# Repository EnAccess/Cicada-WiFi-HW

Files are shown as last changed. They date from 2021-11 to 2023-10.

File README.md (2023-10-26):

<p align="center">
  <a href="https://github.com/EnAccess/Cicada-WiFi-HW">
    Cicada GSM
  </a>
</p>
<p align="center">
    <em>IoT Communications Module for Energy Access. A quick way to get production ready, bi-directional communications for your IoT embedded device.</em>
</p>
<p align="center">
  
  
  <a href="https://github.com/EnAccess/Cicada-WiFi-HW/blob/main/LICENSE" target="_blank">
    
  </a>
</p>

---

# Cicada-WiFi-HW

Cicada WiFi HW - IoT Communications Module for Energy Access.
An easy way to get production ready, bi-directional communications for your IoT embedded device.

This repository contains the hardware design for supported Cicada wifi. This HW is designed to operate with host running cicada-FW. <https://github.com/EnAccess/Cicada-FW>

## Manufacturing files

If you are only interested in manufacturing the PCBs, you only need files in the /manufacturing/ directory. send them to your contract manufacturer of choice,Some examples of other turnkey PCBA manufacturers are:

| Manufacturers |
|---------------|
| JLCPCB |
| PCBCart |
| Bittele |

you can also get a plug and play module (might require manual FW update) from <https://www.seeedstudio.com/Enaccess-Okra-Cicada-Wifi-Communication-PCBA-p-5421.html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>.

The /manufacturing/production directory contains the PCB Gerber/drill files, the BOM, and assembly instructions.

## Source files

If you'd like to take a look at the schematics and PCB layout, first, make sure you have a fresh version of KiCAD. It's a free and open source electronics design tool,
and can be downloaded from <http://kicad.org>. Make sure you are not using an old version that some Linux distributions might be still shipping.

## File structure

The schematics and related files live under the /design/ directory:

| Directory | Content |
|---|---|
| /design/doc/datasheets/ | Datasheets for some of the components used. These files are not covered by this project's open source licence |
| /design/doc/Schematic | Schematics exported as PDF. |
| /design/source/kicad/ | Kicad source files for the CICADA WIFI hardware inculding component lib files and bom generation script |
| /manufacturing/gerber/ |  these are set of files which gives information on different layers used in the project (copper layers, silk screen , court yard and other relevent files) |
| /manufacturing/stackup/ | Text file containing the details of the PCB material and stackup |
| /manufacturing/pick and place/ | Pick and place files describing component locations and orientations for PCB Assembly |
| /manufacturing/nc drill/ | NC Drill files describing type and specification of PCB drill holes (vias, through holes, mounting holes etc) |
| /manufacturing/BOM/ | BOM contains the imformation of all the components used in WiFi cicad. directely generated from Kicad using the bom genration script  |

## A quick look at the schematics

The schematics is based on ESP-07S ESP8266 Serial WiFi Module, The module supports standard IEEE802.11 b/g/n agreement, complete TCP/IP protocol stack and capable of
+20dBm output power in 802.11b mode. For more information the data sheet of the module will be available in /design/doc/datasheets/ directory

## Host interface

The Cicada uses a 2x10 female pin socket that fits perfectly in a 2x8 shrouded pin header on the host side. (We don’t use a 2x8 female pin socket because it is possible to
do a off-by-one insertion with it). The host interface provides a way for the host to detect the presence of a Cicada board,transmit and receive data, and distinguish
between different Cicada communications boards (Cicada 2g, Cicada 4g):

| Pin | Discription |
|---|---|
| Pin-1 Vref(3v3) | Logic level VCC reference provided by host. only used for VER_1/2 as described below. Other cicadas Vref may be used for level shifiting for I/O pins |
| Pin-2 VER_1 | Board version pin (represents, what type of cicada it is 2g,4g or WiFi), for more information please check schematics |
| Pin-3 GND |  |
| Pin-4 VER_2 | Board version pin (represents, latest production release version) |
| Pin-5 5V | 5v Power provided by host. Peak curent consuption <200mA |
| Pin-6 GND |  |
| Pin-7 GND |  |
| Pin-8 POWER_EN | Drive high to enable power |
| Pin-9 NC |  |
| Pin-10 NC |  |
| Pin-11 NC |  |
| Pin-12 UART_Tx_3V3 | Should be connected to host's UART_TX |
| Pin-13 UART_Rx_3V3 | Should be connected to host's UART_RX |
| Pin-14 MODE_SELECT |  Pull low to Enable ESP-8266 FW flashing mode, |
| Pin-15 NC |  |
| Pin-16 n_RESET| drive low to reset, drive at 1.8 - 3.3v during normal operation |

## Power

Board is powered up by single-chip SMPS (HX3406) to convert 5v down to 3.3v required by ESP-07S(ESP8266 Serial WiFi Module WiFi module).

## Antenna

The ESP-07S ESP8266 Serial WiFi Module has a on board IPEX connector, which can be extended to an antenna using U.FL cable

## ESP8266 operating MODEs

| ESP8266 operating MODE  | GPIO15 | GPIO0 | GPIO2 |
|---|---|---|---|
| FW flashing | low | low | high |
| Normal/UART | low | high | high |

# Need to Flash the module with the latest FW??

## Requirements

- USB to serial TTL adapter hardware
- esptool.py (Ubuntu package esptool or GitHub - espressif/esptool: Espressif SoC serial bootloader utility)
- Wifi firmware: <https://www.espressif.com/sites/default/files/ap/ESP8266_NonOS_AT_Bin_V1.7.4.zip>
Note: Make sure the USB to serial adapter is set to 3.3V IO voltage! (usually there is a jumper for that)

## Setup

Connect Wifi module and USB adapter

| Cicada WiFi | USB adapter |
|---|---|
| 5V0 | 5V0 |
| GND | GND |
| POWER_EN | 3V3 |
| UART_RX_3V3 | Rx |
| UART_TX_3V3 | Tx |
| MODE_SELECT | GND |

The module should now respond to AT commands. You can check this by running the serial_linux example from Cicada.

## Flash firmware

- Unzip the firmware package and go to ESP8266_NonOS_AT_Bin_V1.7.4/bin directory. Then run this command to flash:
esptool.py -p /dev/ttyUSB0 --chip esp8266 write_flash --flash_size 4MB-c1 0x00000 boot_v1.7.bin 0x01000 at/1024+1024/user1.2048.new.5.bin 0x1fc000   esp_init_data_default_v08.bin 0xfe000 blank.bin 0x1fb000 blank.bin 0x1fe000 blank.bin

After flashing, remove the grounding of IO0(MODE_SELECT) again, so it’s free floating. The Cicada module should now be ready for installation.

# Future Improvements

- invitigate on adding an amplifier to the design for range improvemnet

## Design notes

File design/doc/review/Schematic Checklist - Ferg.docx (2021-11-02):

# Schematic Design Review checklists

Part / Assembly | P-1000072
Revision
Review Date
Review Type
Reviewed By

# Schematic Review

# | Check | Completed | Comment

| Individual Components
| Component links match footprint and annotations
| All nets are limited to below the max V, I etc of the component | Y
| Adequate filtering is provided where needed. Consider ferrites, series resistors and TVS on signals going externally. Consider filtering on power lines, esp is low noise power is needed for analog signals | y
| Race conditions checked | y
| Starts up into known/controlled state | y
| Layout notes are present where required | y
| Differential pairs specified where necessary | y
| Compare to ref. design if available | y
| All pins connected to sensible things | y
| Polarisation checked | y
| Power Lines
| Input power lines fused and protected | na
| For automotive use, Two ceramic capacitors placed in series across input lines and at right angles to each other. | na
| Power limiting behaviour verified | na
| Power supplies are adequate | y
| IO
| Check pinouts for all external connectors match the connector they mate with | y
| All outside lines filtered for RFI | y
| All necessary lines protected against static discharge | y
| Other
| Overview sheet is present | na
| Behaviour of entire schematic as expected | y
| No 4 way joins, all other nets are joined where they should be | y
| Test points where required | y
| Signal LEDs where required | y
| Debug headers for signals that may need external access | y
| Confirm I2C has pull ups | na
| Confirm Tx/Rx nets swapped as necessary (for UART, PCIe, etc etc) | y
| Component Selection
| Temp Grade
| Ratings (eg automotive)
| Suitable Functionality
| Thermal Dissipation
| Thermal Derating
| Current Handling
| Voltage
| DC Bias (Cap and Inductor)
| DNPs

# Review Area

# | Sheet | Component/Net | Type | Comment | Recommended action | Designers response /action taken | Review Response | Designers response /action taken 2

| | All | | Sch isn’t readable in some areas. Sch should be super easy to ready, it’s purpose is to convey the function of the circuit as quickly, easily, and unambigiously to the ready as possible | No overlapping text, good spacing, minimise unlinked net label etc | Done | Looks ok, more spacing never really hurts. Also making sure labels are in consistent location and orientation makes things more readable.
| | R7/R10 | | Do we need these? I think they will just mess up the signal path? | | | ok
| | L3/L4 | | Should these be between caps and U2, or should the caps be between U2 and L3/4? | | I have followed the reference design, which chee has used for review, but it was not using the same IC though | ok
| | U3 | | Add decoupling caps next to U3 | I would add a couple of 1uF and 0.1uF caps next to ESP-07S VCC | Added | ok
| | U3 | | U3 EN signal should have 0R resistor | | Followed ESPWROOM-02U datasheet and added RC network, as it was recommended | ok
| | U3 | | Add a series 22R or 100R resistor to the UART Tx and Rx lines. These can be used to improve signal quality and to protect the device in case of MCU failure or something | | Done Looks like it’s been taken care on MCU side | ok
| | VCC | | Rename VCC net to 3V3 | | Done | ok
| | 5v | | Rename to 5V0 | | Done | Missed one lower case ‘v’ 3v3 on U3 EN pin
| | U1 | | Add output current rating next to output (800mA?) | | Done | ok
| | J1 | | Change name of 3v3 to indicate it is only for level shifting purposes | | Done | ok
| | Electrical Char section | | This is awesome, I would rename it power consumption, Add the 800mA output limit of the HX3406, (and possibly put it down near the PSU section?) | | Done | ok
| | U2 | | Was there an app not for this chip that you referenced? | | I have followed the reference design, which chee has used for review, but it was not using the same IC though. https://okrasolar.slack.com/archives/CERGXCN8K/p1629262801000400?thread_ts=1629091767.000800&cid=CERGXCN8K | ok
| | D1 | | Adding ESD diode is a very good call (the SE2604L states it is an ESD sensitive device). Should we add one to the RF input as well? (most assembly should be in ESD safe env, but given this is an oen source design it might be better same than sorry | | Done | Ok. I’m not sure if we will want to load the 100pf caps on the rf lines.. Are they part of the App note?
| | U2/R11 | | We should add a DNP 1k pull up resistor here as well in case we just want to have it enable all the time. U2 also has a build in 10k pull down on the pin so we could possible get rid of R11 (or at least DNP) | | Done | ok
| | TP30 | | I would put the pair of bottom side (and one top side) GND test points in the power section as they are one of the “Power” nets | | TP30 is not a ground | There are a bunch of GND test points on the GND pins from each IC, I would suggest putting the power test points in the power section for clarity?
| | U2 | | Add a layout note saying that the RF path needs to be single ended 50R controlled impedance tracks, and that the tracs should be as should as possible and follow RF layout best practice. | | Will do while working on layout | Can we add the note to the Sch? The idea is to have the layout note on the Sch so that if someone else needs to make layout changes later they have all the needed info.
| | Logos | | Can we add an open hardware logo? | | Not sure what I should do here! | Low priority, don’t worry about it
| | D1 | | Value should be set to MPN | | Done
| | J3 Host connector | | Pin14 in NC on edamame. | | Move mode select to pin 15 (nCS pin on edamame)
| | U1 Pin 5 | | 4-way ‘+’ net connection off U1 pin 5 is not recommended as the circle can hide a missed connection. | | Change it to two three way ‘T’ joins

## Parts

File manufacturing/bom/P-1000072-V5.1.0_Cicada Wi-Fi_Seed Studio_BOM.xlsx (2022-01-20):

Designator | MNP | Qty | Link | Description | Manufacturer | SMT/THT | Source | SPN
C1, C2, C21, C22, C24 | GR108M010F12RR0VL4FP0 | 5 | https://www.lcsc.com/product-detail/Aluminum-Electrolytic-Capacitors-Leaded_CX-Dongguan-Chengxing-Elec-GR108M010F12RR0VL4FP0_C3299.html | 1000uF 10v | Dongguan Chengxing Elec | THT | lcsc | C3299
C3, C19 | 0603B104K500NT | 2 | https://www.lcsc.com/product-detail/Multilayer-Ceramic-Capacitors-MLCC-SMD-SMT_FH-Guangdong-Fenghua-Advanced-Tech-0603B104K500NT_C30926.html | 100nF 16v X7R | Guangdong Fenghua Advanced Tech | SMT | lcsc | C30926
C4, C20 | 0805B106K160NT | 2 | https://www.lcsc.com/product-detail/Multilayer-Ceramic-Capacitors-MLCC-SMD-SMT_FH-Guangdong-Fenghua-Advanced-Tech-0805B106K160NT_C92341.html | 10uF 16v X7R | Guangdong Fenghua Advanced Tech | SMT | lcsc | C92341
C6, C8, C14, C29 | CC0402MRX5R6BB104 | 4 | https://www.lcsc.com/product-detail/Multilayer-Ceramic-Capacitors-MLCC-SMD-SMT_YAGEO-CC0402MRX5R6BB106_C962143.html | 100nF 10v X5R | Yageo | SMT | lcsc | C2171572
C9 | CC0402MRX5R6BB106 | 1 | https://www.lcsc.com/product-detail/Multilayer-Ceramic-Capacitors-MLCC-SMD-SMT_YAGEO-CC0402MRX5R6BB106_C962143.html | 10uF 10v X5R | Yageo | SMT | lcsc | C962143
C16 | 0402CG101J500NT | 1 | https://www.lcsc.com/product-detail/Multilayer-Ceramic-Capacitors-MLCC-SMD-SMT_FH-Guangdong-Fenghua-Advanced-Tech-0402CG101J500NT_C1546.html | 100pF C0G | Guangdong Fenghua Advanced Tech | SMT | lcsc | C1546
J3 | C30867 | 1 | https://www.lcsc.com/product-detail/Female-Headers_BOOMELE-Boom-Precision-Elec-C30867_C30867.html | Host | Boom Precision Elec | THT | lcsc | C30867
L2 | FPI0403F-3R3M | 1 | https://www.lcsc.com/product-detail/Inductors-SMD_SHOU-HAN-CY43-3-3UH_C2929417.html | 3.3uH 2.1A | SHOU HAN | SMT | lcsc | C2929417
R1, R7 | 0402WGF4022TCE | 2 | https://www.lcsc.com/product-detail/Chip-Resistor-Surface-Mount_UNI-ROYAL-Uniroyal-Elec-0402WGF4022TCE_C25893.html | 40.2k | Uni-Royal | SMT | lcsc | C25893
R4, R5, R11 | 0402WGF1002TCE | 3 | https://www.lcsc.com/product-detail/Chip-Resistor-Surface-Mount_UNI-ROYAL-Uniroyal-Elec-0402WGF1002TCE_C25744.html | 10K | Uni-Royal | SMT | lcsc | C25744
R6 | 0402WGJ0000TCE | 1 | https://www.lcsc.com/product-detail/Chip-Resistor-Surface-Mount_UNI-ROYAL-Uniroyal-Elec-0402WGJ0000TCE_C21376.html | 0R | Uni-Royal | SMT | lcsc | C21376
R8 | 0402WGF8871TCE | 1 | https://www.lcsc.com/product-detail/Chip-Resistor-Surface-Mount_UNI-ROYAL-Uniroyal-Elec-0402WGF8871TCE_C36953.html | 8.87k | Uni-Royal | SMT | lcsc | C36953
R9, R10 | 0402WGF220JTCE | 2 | https://www.lcsc.com/product-detail/Chip-Resistor-Surface-Mount_UNI-ROYAL-Uniroyal-Elec-0402WGF220JTCE_C25092.html | 22R | Uni-Royal | SMT | lcsc | C25092
R12 | 0402WGF2262TCE | 1 | https://www.lcsc.com/product-detail/Chip-Resistor-Surface-Mount_UNI-ROYAL-Uniroyal-Elec-0402WGF2262TCE_C26960.html | 22.6K | Uni-Royal | SMT | lcsc | C26960
R13 | 0402WGF8662TCE | 1 | https://www.lcsc.com/product-detail/Chip-Resistor-Surface-Mount_UNI-ROYAL-Uniroyal-Elec-0402WGF8662TCE_C19709.html | 86.6k | Uni-Royal | SMT | lcsc | C423187
U1 | HX3406 | 1 | https://datasheet.lcsc.com/lcsc/1912111437_HX-hengjiaxing-HX3406_C296282.pdf | 3V3, 800mA DC-DC Converter | XI'AN Aerosemi Tech | SMT | lcsc | C83224
U3 | ESP-07S | 1 | https://www.lcsc.com/product-detail/WiFi-Modules_Ai-Thinker-ESP-07S_C82895.html | ESP-07S WiFi Module | Ai-Thinker | SMT | lcsc | C82895

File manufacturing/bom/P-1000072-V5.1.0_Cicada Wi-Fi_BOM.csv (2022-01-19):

Source: | F:\office\okra\okrasolar\svn\P-1000072_Cicada Wi-Fi\design\source\kicad\P-1000072_Cicada Wi-Fi.sch
Date: | 1/19/2022 1:28:17 PM
Tool: | Eeschema (5.1.10)-1
Generator: | F:\office\okra\okrasolar\svn\okra_kicad_lib\scripts/OKRA_bom_csv_grouped_by_value_mpn_dnp.py
Component Count: | 34
Collated Components:
Designator | Qty | DNP | Value | Description | Manufacturer | MPN | Footprint | SMT/THT | SOURCE | SRCPN | Alternate Manufacturer 1 | Alternate MPN 1 | Alternate Manufacturer 2 | Alternate MPN 2
C1, C2, C21, C22, C24 | 5 |  | 1000uF 10v |  | Dongguan Chengxing Elec | GR108M010F12RR0VL4FP0 | Capacitor_THT:CP_Radial_D8.0mm_P3.50mm | THT | lcsc | C3299
C3, C19 | 2 |  | 100nF 16v X7R |  | Guangdong Fenghua Advanced Tech | 0603B104K500NT | Capacitor_SMD:C_0603_1608Metric | SMT | lcsc | C30926
C4, C20 | 2 |  | 10uF 16v X7R |  | Guangdong Fenghua Advanced Tech | 0805B106K160NT | Capacitor_SMD:C_0805_2012Metric | SMT | lcsc | C92341
C6, C8, C14, C29 | 4 |  | 100nF 10v X5R |  | YAGEO | CC0402MRX5R6BB104 | Capacitor_SMD:C_0402_1005Metric | SMT | lcsc | C2171572
C9 | 1 |  | 10uF 10v X5R |  | YAGEO | CC0402MRX5R6BB106 | Capacitor_SMD:C_0402_1005Metric | SMT | lcsc | C962143
C16 | 1 |  | 100pF C0G |  | Guangdong Fenghua Advanced Tech | 0402CG101J500NT | Capacitor_SMD:C_0402_1005Metric | SMT | lcsc | C1546
H1, H2 | 2 | DNP | MountingHole_Pad |  |  |  | MountingHole:MountingHole_3.2mm_M3_ISO14580_Pad | N/A
J3 | 1 |  | Host | Generic 2x10 2.54mm Female | Boom Precision Elec | C30867 | Cicada-footprints:PinSocket_2x08_P2.54mm_Vertical_padded | THT | lcsc | C30867
L2 | 1 |  | 3.3uH 2A |  | TAITEC | FPI0403F-3R3M | Cicada-footprints:L_4030_Handsoldering | SMT | lcsc | C304284
LOGO1 | 1 | DNP | SYM_Hot_Small |  |  |  | Cicada-footprints:okra_logo_copper_2 | N/A
PCB1 | 1 | DNP | WiFi Cicada PCB |  |  |  |  | N/A
R1, R7 | 2 |  | 40.2k | 1%,100ppm | UNI ROYAL | 0402WGF4022TCE | Resistor_SMD:R_0402_1005Metric | SMT | lcsc | C25893
R4, R5, R11 | 3 |  | 10K | 1%, 100ppm | UNI-ROYAL | 0402WGF1002TCE | Resistor_SMD:R_0402_1005Metric | SMT | lcsc
R6 | 1 |  | 0R | 5% 100ppm | UNI-ROYAL | 0402WGJ0000TCE | Resistor_SMD:R_0402_1005Metric | SMT | lcsc | C21376
R8 | 1 |  | 8.87k | 1% 100ppm | UNI ROYAL | 0402WGF8871TCE | Resistor_SMD:R_0402_1005Metric | SMT | lcsc | C36953
R9, R10 | 2 |  | 22R |  | UNI ROYAL | 0402WGF220JTCE | Resistor_SMD:R_0402_1005Metric | SMT | lcsc | C25092
R12 | 1 |  | 22.6K | 1% 100ppm | UNI ROYAL | 0402WGF2262TCE | Resistor_SMD:R_0402_1005Metric | SMT | lcsc | C26960
R13 | 1 |  | 86.6k | 1% 100ppm | UNI ROYAL | 0402WGF8662TCE | Resistor_SMD:R_0402_1005Metric | SMT | lcsc | C423187
U1 | 1 |  | HX3406 |  | XI'AN Aerosemi Tech | HX3406 | Package_TO_SOT_SMD:TSOT-23-5 | SMT | lcsc | C83224
U3 | 1 |  | ESP-07S |  | Ai-Thinker | ESP-07S | Cicada-footprints:ESP-07S | SMT | lcsc | C82895

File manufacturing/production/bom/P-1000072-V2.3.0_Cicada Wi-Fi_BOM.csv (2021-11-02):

Source: | F:\office\okra\okrasolar\svn\P-1000072_Cicada Wi-Fi\design\source\kicad\P-1000072_Cicada Wi-Fi.sch
Date: | 9/17/2021 9:25:19 AM
Tool: | Eeschema (5.1.10)-1
Generator: | F:\office\okra\okrasolar\svn\okra_kicad_lib\scripts/OKRA_bom_csv_grouped_by_value_mpn_dnp.py
Component Count: | 58
Collated Components:
Designator | Qty | DNP | Value | Description | Manufacturer | MPN | Footprint | SMT/THT | SOURCE | SRCPN | Alternate Manufacturer 1 | Alternate MPN 1 | Alternate Manufacturer 2 | Alternate MPN 2
C1 | 1 | DNP | 1000uF 10v |  | Dongguan Chengxing Elec | GR108M010F12RR0VL4FP0 | Capacitor_THT:CP_Radial_D8.0mm_P3.50mm | THT | lcsc | C3299
C2, C21, C22, C24 | 4 |  | 1000uF 10v |  | Dongguan Chengxing Elec | GR108M010F12RR0VL4FP0 | Capacitor_THT:CP_Radial_D8.0mm_P3.50mm | THT | lcsc | C3299
C3, C19 | 2 |  | 100nF 16v X7R |  | Guangdong Fenghua Advanced Tech | 0603B104K500NT | Capacitor_SMD:C_0603_1608Metric | SMT | lcsc | C30926
C4, C20 | 2 |  | 10uF 16v X7R |  | Guangdong Fenghua Advanced Tech | 0805B106K160NT | Capacitor_SMD:C_0805_2012Metric | SMT | lcsc | C92341
C5, C6, C8, C12, C14, C17, C26, C29 | 8 |  | 100nF 10v X5R |  | YAGEO | CC0402MRX5R6BB104 | Capacitor_SMD:C_0402_1005Metric | SMT | lcsc | C2171572
C7, C28 | 2 | DNP | 100pF C0G |  |  |  | Capacitor_SMD:C_0402_1005Metric
C9, C13, C15, C27 | 4 |  | 10uF 10v X5R |  | YAGEO | CC0402MRX5R6BB106 | Capacitor_SMD:C_0402_1005Metric | SMT | lcsc | C962143
C10, C23 | 2 | DNP | 10pF C0G |  |  |  | Capacitor_SMD:C_0402_1005Metric
C11, C16, C18, C25 | 4 |  | 100pF C0G |  | Guangdong Fenghua Advanced Tech | 0402CG101J500NT | Capacitor_SMD:C_0402_1005Metric | SMT | lcsc | C1546
D1, D2 | 2 |  | LXES15AAA1-153 |  | Murata Electronics | LXES15AAA1-153 | Diode_SMD:D_0402_1005Metric | SMT | lcsc | C86141
H1, H2 | 2 | DNP | MountingHole_Pad |  |  |  | MountingHole:MountingHole_3.2mm_M3_ISO14580_Pad | N/A
J1, J2 | 2 |  | U.FL |  | Hirose | U.FL-R-SMT-1(80) | edemame-custom-footprints:U.FL_Molex_MCRF_73412-0110_Vertical | SMT | lcsc | C88374
J3 | 1 |  | Host | Generic 2x10 2.54mm Female | Boom Precision Elec | C30867 | edemame-custom-footprints:PinSocket_2x08_P2.54mm_Vertical_padded | THT | lcsc | C30867
L1 | 1 |  | 1.2nH |  | Guangdong Fenghua Advanced Tech | VHF100505H1N2ST | Capacitor_SMD:C_0402_1005Metric | SMT | lcsc | C90187
L2 | 1 |  | 3.3uH 2A |  | TAITEC | FPI0403F-3R3M | edemame-custom-footprints:L_4030_Handsoldering | SMT | lcsc | C304284
L3 | 1 |  | 1nH |  | Guangdong Fenghua Advanced Tech | VHF100505HQ1N0ST | Capacitor_SMD:C_0402_1005Metric | SMT | lcsc | C395051
L4 | 1 |  | 10nH |  | WE | 7447860110 | Capacitor_SMD:C_0603_1608Metric | SMT | Digi-key | 732-7447860110TR-ND
LOGO1 | 1 | DNP | SYM_Hot_Small |  |  |  | edemame-custom-footprints:okra_logo_copper_2 | N/A
PCB1 | 1 | DNP | WiFi Cicada PCB |  |  |  |  | N/A
R1, R7 | 2 |  | 40.2k | 1%,100ppm | UNI ROYAL | 0402WGF4022TCE | Resistor_SMD:R_0402_1005Metric | SMT | lcsc | C25893
R2, R6 | 2 |  | 0R | 5% 100ppm | UNI-ROYAL | 0402WGJ0000TCE | Resistor_SMD:R_0402_1005Metric | SMT | lcsc | C21376
R3 | 1 |  | 1K | 1%, 100ppm | UNI-ROYAL | 0402WGJ0102TCE | Resistor_SMD:R_0402_1005Metric | SMT | lcsc | C25543
R4, R5, R11 | 3 |  | 10K | 1%, 100ppm | UNI-ROYAL | 0402WGF1002TCE | Resistor_SMD:R_0402_1005Metric | SMT | lcsc
R8 | 1 |  | 8.87k | 1% 100ppm | UNI ROYAL | 0402WGF8871TCE | Resistor_SMD:R_0402_1005Metric | SMT | lcsc | C36953
R9, R10 | 2 |  | 22R |  | UNI ROYAL | 0402WGF220JTCE | Resistor_SMD:R_0402_1005Metric | SMT | lcsc | C25092
R12 | 1 |  | 22.6K | 1% 100ppm | UNI ROYAL | 0402WGF2262TCE | Resistor_SMD:R_0402_1005Metric | SMT | lcsc | C26960
R13 | 1 | DNP | 22.6K | 1% 100ppm | UNI ROYAL | 0402WGF2262TCE | Resistor_SMD:R_0402_1005Metric | SMT | lcsc | C26960
U1 | 1 |  | HX3406 |  | XI'AN Aerosemi Tech | HX3406 | Package_TO_SOT_SMD:TSOT-23-5 | SMT | lcsc | C83224
U2 | 1 |  | SE2604L |  | SkyWork | SE2604L | edemame-custom-footprints:SE2604L | SMT | Digikey | 863-1370-2-ND
U3 | 1 |  | ESP-07S |  | Ai-Thinker | ESP-07S | edemame-custom-footprints:ESP-07S | SMT | lcsc | C82895

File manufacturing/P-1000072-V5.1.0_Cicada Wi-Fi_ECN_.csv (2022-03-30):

Bom_Level | Parent Part | Part Number | Designator | Change Description | Old Version Number | New Version Number | Release Date | Change Type (modify,remove,add) | Design/Document Change | Change Over Process (Running, Immediate) | Old CM Part Number | New CM Part Number | Old MPN | New MPN | Old Manufacturer | New Manufacturer | Reason for Change
1 |  | P-1000072_Cicada Wi-Fi | PCB1 | Changed part ref dimensions in all silk and fab layers | 5.0.0 | 5.1.0 | 2022-03-22 | modify | Design | Immediate | NA | NA | NA | NA | NA | NA | Production output file improvements
1 |  | P-1000072_Cicada Wi-Fi | PCB1 | Changed version in slik screen from v4 to v5 | 5.0.0 | 5.1.0 | 2022-03-22 | modify | Design | Immediate | NA | NA | NA | NA | NA | NA | changes in PCB, general improvements
1 |  | P-1000072_Cicada Wi-Fi | PCB1 | captured U3 to POS files, changed to U3 to SMT | 5.0.0 | 5.1.0 | 2022-03-22 | modify | Design | Immediate | NA | NA | NA | NA | NA | NA | Production output file improvements
1 |  | P-1000072_Cicada Wi-Fi | PCB1 | changed L2 footprint dimension | 4.0.2 | 5.0.0 | 2022-03-14 | modify | Design | Immediate | NA | NA | NA | NA | NA | NA | parts recommended footprint dimension mismatch
1 |  | P-1000072_Cicada Wi-Fi | PCB1 | Moved TP 9 (RST) testpoint to different location | 4.0.2 | 5.0.0 | 2022-03-14 | modify | Design | Immediate | NA | NA | NA | NA | NA | NA | sch to pcb update mismatch
1 |  | P-1000072_Cicada Wi-Fi | PCB1 | Moved TP 2 (5V) testpoint to different loaction | 4.0.2 | 5.0.0 | 2022-03-14 | modify | Design | Immediate | NA | NA | NA | NA | NA | NA | sch to pcb update mismatch
1 |  | P-1000072_Cicada Wi-Fi | PCB1 | Moved parts R7,C16,R1,C19,C20,U1,L2 in PCB | 4.0.2 | 5.0.0 | 2022-03-14 | modify | Design | Immediate | NA | NA | NA | NA | NA | NA | To Fit L2 after dimension change
1 |  | P-1000072_Cicada Wi-Fi | PCB1 | Cleaned Top and Bottom Fabrication Layer. | 4.0.1 | 4.0.2 | 2022-01-20 | modify | Design | Immediate | NA | NA | NA | NA | NA | NA | Production output file improvements
1 |  | P-1000072_Cicada Wi-Fi | PCB1 | updated R13 to be populated | 4.0.0 | 4.0.1 | 2022-01-19 | modify | Design | Immediate | NA | NA | NA | NA | NA | NA | BOM mismatch
1 |  | P-1000072_Cicada Wi-Fi | PCB1 | cleaned schematics, R13 data matched with spec | 4.0.0 | 4.0.1 | 2022-01-19 | modify | Design | Immediate | NA | NA | NA | NA | NA | NA | Schematics improvements and credibility
1 |  | P-1000072_Cicada Wi-Fi | PCB1 | Updated PCB (Pour,Drils and version number in silk) | 4.0.0 | 4.0.1 | 2022-01-19 | modify | Design | Immediate | NA | NA | NA | NA | NA | NA | PCB layout Improvements
1 |  | P-1000072_Cicada Wi-Fi | R12 | R12 Changed from 150K-“RC0402FR-0786K6L” to 22.6K-”0402WGF8662TCE” | 3.0.0 | 4.0.0 | 2021-11-23 | modify | Design | Immediate | NA | NA | RC0402FR-0786K6L | 0402WGF8662TCE | Yageo | Uniroyal | Board version resistor changed 6.1 to 6.3
1 |  | P-1000072_Cicada Wi-Fi | R13 | R13 Changed from 150K-”RC0402JR-07150KL” to 86.6K-”0402WGF8662TCE” | 3.0.0 | 4.0.0 | 2021-11-23 | Add | Design | Immediate | NA | NA | RC0402JR-07150KL | 0402WGF8662TCE | Yageo | Uniroyal | Corrected version resistor value
1 |  | P-1000072_Cicada Wi-Fi | PCB1 | R12,R13 Board Version resistor Pulled up with Vref(3V3) from J3 connector Pin 1 instead of onboard 3V3 Power supply | 3.0.0 | 4.0.0 | 2021-11-23 | modify | Design | Immediate | NA | NA | NA | NA | NA | NA | Version resistors are measured by MCU ADC and should be referenced to host 3V3
1 |  | P-1000072_Cicada Wi-Fi |  | Schematic: Moved 3V3 Testpoints to Power supply section | 3.0.0 | 4.0.0 | 2021-11-23 | modify | Document | Immediate | NA | NA | NA | NA | NA | NA | Layout improvements
1 |  | P-1000072_Cicada Wi-Fi | PCB1 | Cleaned up PCB (Copper pour, ground vias,Tracks) | 3.0.0 | 4.0.0 | 2021-11-23 | modify | Design | Immediate | NA | NA | NA | NA | NA | NA | Layout improvements
1 |  | P-1000072_Cicada Wi-Fi | PCB1 | R5 Replaced as a PULL-UP resister to GPIO0, previously it was connected series between U1 Pin 12 and J1 Pin 14 | 2.3.0 | 3.0.0 | 2021-11-03 | modify | Design | Immediate | NA | NA | NA | NA | NA | NA | Bug/Design improvements
1 |  | P-1000072_Cicada Wi-Fi | PCB1 | R11 Replaced as a PULL-UP resister to nRST, previously it was connected series between U1 Pin 0 and J1 Pin 16 | 2.3.0 | 3.0.0 | 2021-11-03 | modify | Design | Immediate | NA | NA | NA | NA | NA | NA | Bug/Design improvements
1 |  | P-1000072_Cicada Wi-Fi | C5,C12.C17,C26,C13, C15, C27,C10, C23,C11, C18, C25,D1, D2 ,J1,J2,L1,L3,L4,R2,R3,U2 | Removed amplifier circuit completely from PCB | 2.3.0 | 3.0.0 | 2021-11-03 | remove | Design | Immediate | NA | NA | NA | NA | NA | NA | NA
1 |  | P-1000072_Cicada Wi-Fi |  | updated Pick and Place .POS file (U2 and U3 has been changed to SMD) | 2.2.0 | 2.3.0 | 2021-10-05 | modify | Document | Immediate | NA | NA | NA | NA | NA | NA | M-pack improvement
1 |  | P-1000072_Cicada Wi-Fi | PCB1 | updated front mask layer (Clearance: 0.05 and MIN Width: 0.1 ) | 2.1.0 | 2.2.0 | 2021-09-17 | modify | Design | Immediate | NA | NA | NA | NA | NA | NA | PCB improvements
1 |  | P-1000072_Cicada Wi-Fi | C2, C21, C22, C24, L4, R9, R10, R12, R13 | BOM Mismatch Update | 2.0.0 | 2.1.0 | 2021-09-17 | modify | Design | Immediate | NA | NA | NA | NA | NA | NA | BOM mismatch
1 |  | P-1000072_Cicada Wi-Fi | PCB1 | improved U3 grounding for RFin and RFout | 1.0.0 | 2.0.0 | 2021-09-02 | modify | Design | Immediate | NA | NA | NA | NA | NA | NA | General improvements
1 |  | P-1000072_Cicada Wi-Fi |  | Added RC network to U3 and U2 Vcc and IO pins | 1.0.0 | 2.0.0 | 2021-09-02 | modify | Design | Immediate | NA | NA | NA | NA | NA | NA | General improvements
1 |  | P-1000072_Cicada Wi-Fi | PCB1 | improved 5V5,3V3 and GND Zones | 1.0.0 | 2.0.0 | 2021-09-02 | modify | Design | Immediate | NA | NA | NA | NA | NA | NA | General improvements
1 |  | P-1000072_Cicada Wi-Fi |  | First release | 0.0.0 | 1.0.0 | 2021-08-25 | Add | Design | Immediate | NA | NA | NA | NA | NA | NA | NA

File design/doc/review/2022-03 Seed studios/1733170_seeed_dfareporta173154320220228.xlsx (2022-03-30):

Seeed DFA report
Project Name： |  | Prepared by: Qiaoyu Lin |  |  |  | Date: 20220228
Item | Problem description 问题描述 | Reference location 影响位置 | Impact 影响 | Image 图片 | Seeed Suggestion 矽递建议 | Customer feedback 客户反馈 | Severity 严重度 | Status 状态
1 | The L2 is not match with dataseet | L2 | couldn't be soldered in the pads well |  | Please update the Gerber to match with datasheet |  | High | open
2 |  |  |  |  |  |  | Middle | open
3 |  |  |  |  |  |  | Middle | open
4 |  |  |  |  |  |  | Middle | open
5 |  |  |  |  |  |  | Middle | open
6 |  |  |  |  |  |  | Middle | open
7 |  |  |  |  |  |  | Middle | open
8 |  |  |  |  |  |  | Middle | open

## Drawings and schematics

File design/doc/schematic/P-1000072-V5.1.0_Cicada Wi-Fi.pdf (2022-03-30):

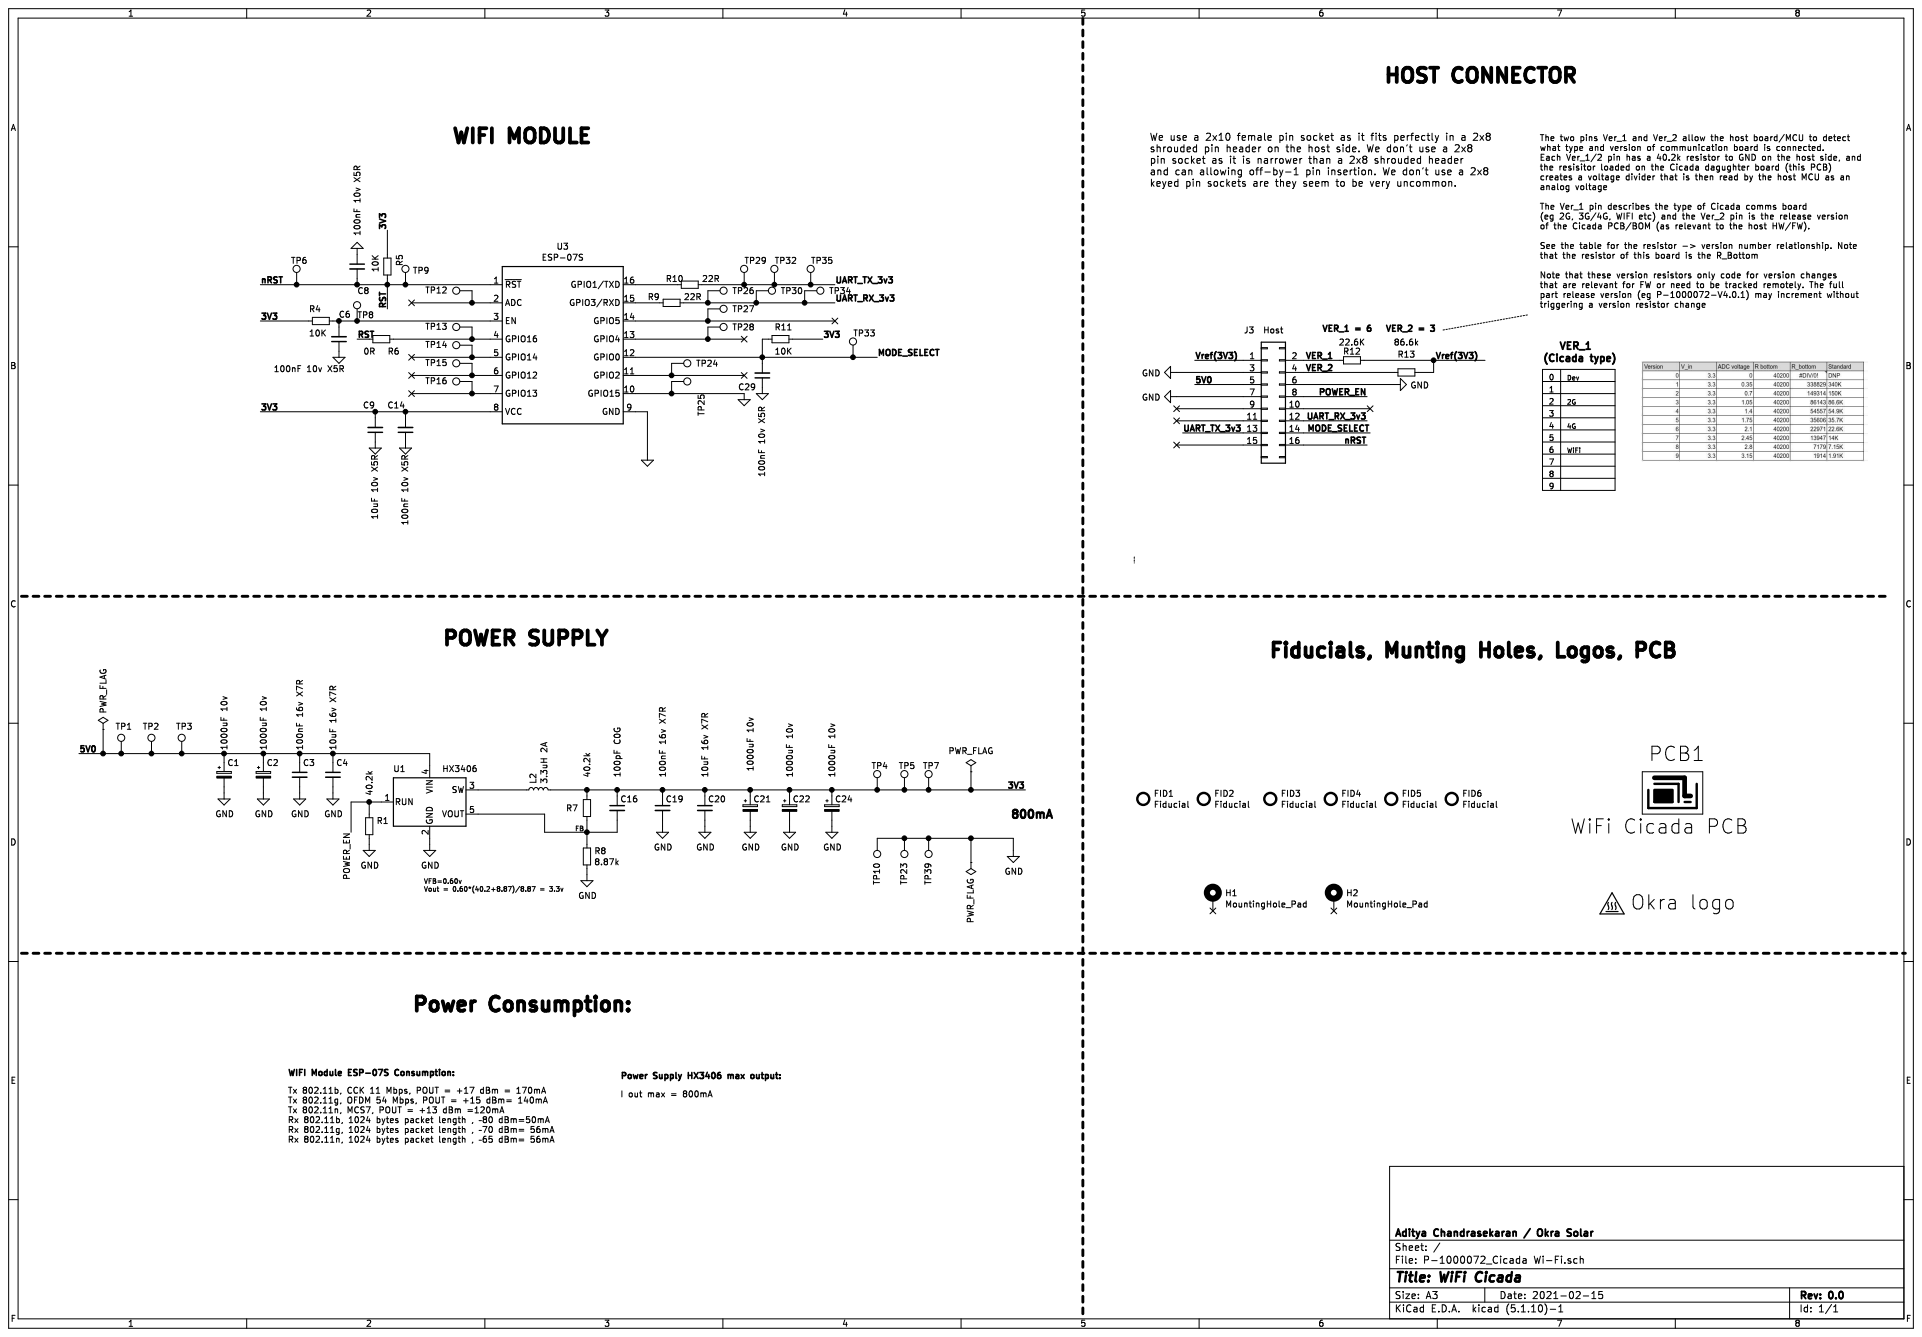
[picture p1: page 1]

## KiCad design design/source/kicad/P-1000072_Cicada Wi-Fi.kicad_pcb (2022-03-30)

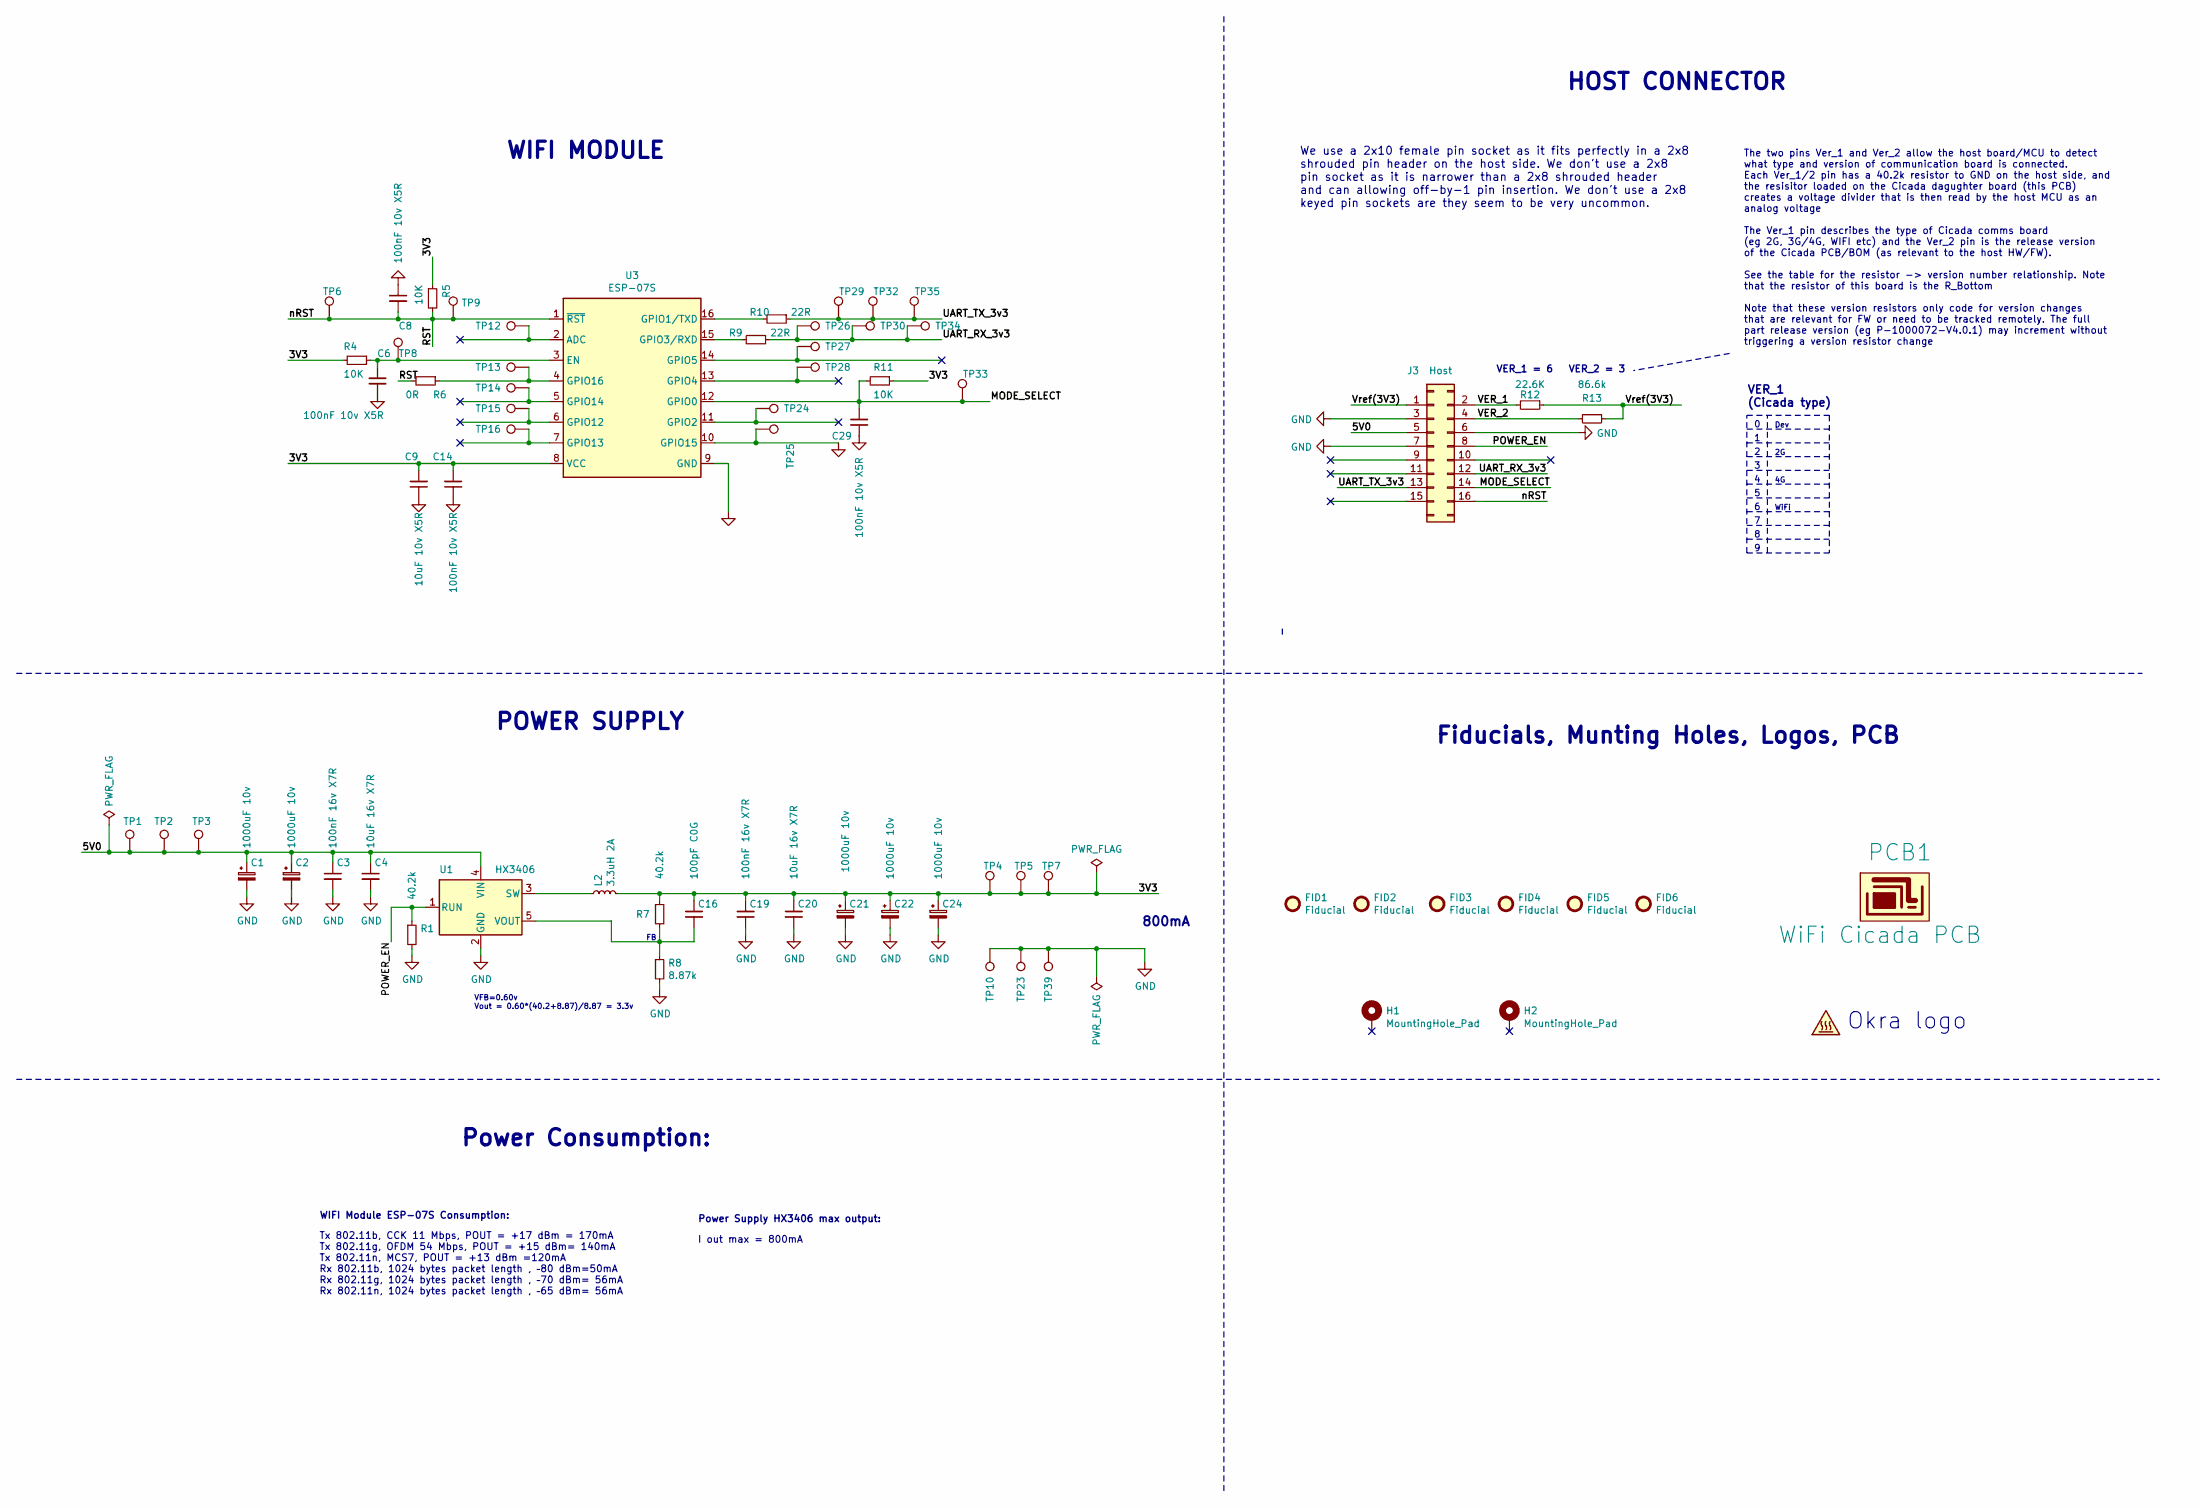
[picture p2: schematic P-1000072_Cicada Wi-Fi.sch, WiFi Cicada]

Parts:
C1, C2, C21, C22, C24: 1000uF 10v; CP_Radial_D8.0mm_P3.50mm; MPN GR108M010F12RR0VL4FP0
C3, C19: 100nF 16v X7R; C_0603_1608Metric; MPN 0603B104K500NT
C4, C20: 10uF 16v X7R; C_0805_2012Metric; MPN 0805B106K160NT
C6, C8, C14, C29: 100nF 10v X5R; C_0402_1005Metric; MPN CC0402MRX5R6BB104
C9: 10uF 10v X5R; C_0402_1005Metric; MPN CC0402MRX5R6BB106
C16: 100pF C0G; C_0402_1005Metric; MPN 0402CG101J500NT
FID1, FID2, FID3, FID4, FID5, FID6: Fiducial; Fiducial_1mm_Mask2mm
H1, H2: MountingHole_Pad; MountingHole_3.2mm_M3_ISO14580_Pad
J3: Host; PinSocket_2x08_P2.54mm_Vertical_padded; MPN C30867
L2: 3.3uH 2A; L_4030_Handsoldering; MPN FPI0403F-3R3M
LOGO1: SYM_Hot_Small; okra_logo_copper_2
PCB1: WiFi Cicada PCB
R1, R7: 40.2k; R_0402_1005Metric; MPN 0402WGF4022TCE
R4, R5, R11: 10K; R_0402_1005Metric; MPN 0402WGF1002TCE
R6: 0R; R_0402_1005Metric; MPN 0402WGJ0000TCE
R8: 8.87k; R_0402_1005Metric; MPN 0402WGF8871TCE
R9, R10: 22R; R_0402_1005Metric; MPN 0402WGF220JTCE
R12: 22.6K; R_0402_1005Metric; MPN 0402WGF2262TCE
R13: 86.6k; R_0402_1005Metric; MPN 0402WGF8662TCE
TP1, TP3: 5v; TestPoint_Pad_D1.5mm
TP2: 5v; TestPoint_THTPad_D1.5mm_Drill0.7mm
TP4, TP8: EN; TestPoint_Pad_D1.5mm
TP5, TP7: Vcc; TestPoint_Pad_D1.5mm
TP6, TP9: RST; TestPoint_Pad_D1.5mm
TP10, TP23, TP39: GND; TestPoint_Pad_D1.5mm
TP12: ADC; TestPoint_Pad_D1.5mm
TP13: P16; TestPoint_Pad_D1.5mm
TP14: P14; TestPoint_Pad_D1.5mm
TP15: P12; TestPoint_Pad_D1.5mm
TP16: P13; TestPoint_Pad_D1.5mm
TP24: P02; TestPoint_Pad_D1.5mm
TP25: P15; TestPoint_Pad_D1.5mm
TP26, TP30, TP34: Rx; TestPoint_Pad_D1.5mm
TP27: AMP_EN; TestPoint_Pad_D1.5mm
TP28: P4; TestPoint_Pad_D1.5mm
TP29, TP32, TP35: Tx; TestPoint_Pad_D1.5mm
TP33: P0; TestPoint_Pad_D1.5mm
U1: HX3406; TSOT-23-5; MPN HX3406
U3: ESP-07S; MPN ESP-07S

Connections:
/3V3: C9.2, C14.2, C16.1, C19.1, C20.1, C21.1, C22.1, C24.1, L2.2, R4.2, R5.1, R7.1, R11.1, TP4.1, TP5.1, TP7.1, U3.8 (VCC)
/5V0: C1.1, C2.1, C3.1, C4.1, J3.5, TP1.1, TP2.1, TP3.1, U1.4 (VIN); also elsewhere on the board
/MODE_SELECT: C29.2, J3.14, R11.2, TP33.1, U3.12 (GPIO0)
/POWER_EN: J3.8, R1.1, U1.1 (RUN)
/RST: C8.2, J3.16, R5.2, R6.2, TP6.1, TP9.1, U3.1 (~RST)
/UART_RX_3v3: J3.12, R9.1, TP26.1, TP30.1, TP34.1
/UART_TX_3v3: J3.13, R10.1, TP29.1, TP32.1, TP35.1
/VER_1: J3.2, R12.2
/VER_2: J3.4, R13.2
/Vref(3V3): J3.1, R12.1, R13.1
GND: C1.2, C2.2, C3.2, C4.2, C6.1, C8.1, C9.1, C14.1, C19.2, C20.2, C21.2, C22.2, C24.2, C29.1, J3.3, J3.6, J3.7, R1.2, R8.2, TP10.1, TP23.1, TP25.1, TP39.1, U1.2 (GND), U3.9 (GND), U3.10 (GPIO15); also elsewhere on the board
unnamed: C6.2, R4.1, TP8.1, U3.3 (EN)
unnamed: C16.2, R7.2, R8.1, U1.5 (VOUT)
unnamed: L2.1, U1.3 (SW)
unnamed: R6.1, TP13.1, U3.4 (GPIO16)
unnamed: R9.2, U3.15 (GPIO3/RXD)
unnamed: R10.2, U3.16 (GPIO1/TXD)
unnamed: TP12.1, U3.2 (ADC)
unnamed: TP14.1, U3.5 (GPIO14)
unnamed: TP15.1, U3.6 (GPIO12)
unnamed: TP16.1, U3.7 (GPIO13)
unnamed: TP24.1, U3.11 (GPIO2)
unnamed: TP27.1, U3.14 (GPIO5)
unnamed: TP28.1, U3.13 (GPIO4)

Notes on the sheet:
The two pins Ver_1 and Ver_2 allow the host board/MCU to detect what type and version of communication board is connected. Each Ver_1/2 pin has a 40.2k resistor to GND on the host side, and the resisitor loaded on the Cicada dagughter board (this PCB) creates a voltage divider that is then read by 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
Dev
WiFi
VER_1 (Cicada type)
Okra logo
VER_1 = 6
VER_2 = 3
We use a 2x10 female pin socket as it fits perfectly in a 2x8 shrouded pin header on the host side. We don't use a 2x8 pin socket as it is narrower than a 2x8 shrouded header and can allowing off-by-1 pin insertion. We don't use a 2x8 keyed pin sockets are they seem to be very uncommon.
VFB=0.60v Vout = 0.60*(40.2+8.87)/8.87 = 3.3v
POWER SUPPLY
Power Consumption:
Tx 802.11b, CCK 11 Mbps, POUT = +17 dBm = 170mA Tx 802.11g, OFDM 54 Mbps, POUT = +15 dBm= 140mA Tx 802.11n, MCS7, POUT = +13 dBm =120mA Rx 802.11b, 1024 bytes packet length , –80 dBm=50mA Rx 802.11g, 1024 bytes packet length , –70 dBm= 56mA Rx 802.11n, 1024 bytes packet length , –65 dBm= 56mA
WIFI MODULE
WIFI Module ESP-07S Consumption:
Power Supply HX3406 max output:
800mA
I out max = 800mA
HOST CONNECTOR
Fiducials, Munting Holes, Logos, PCB

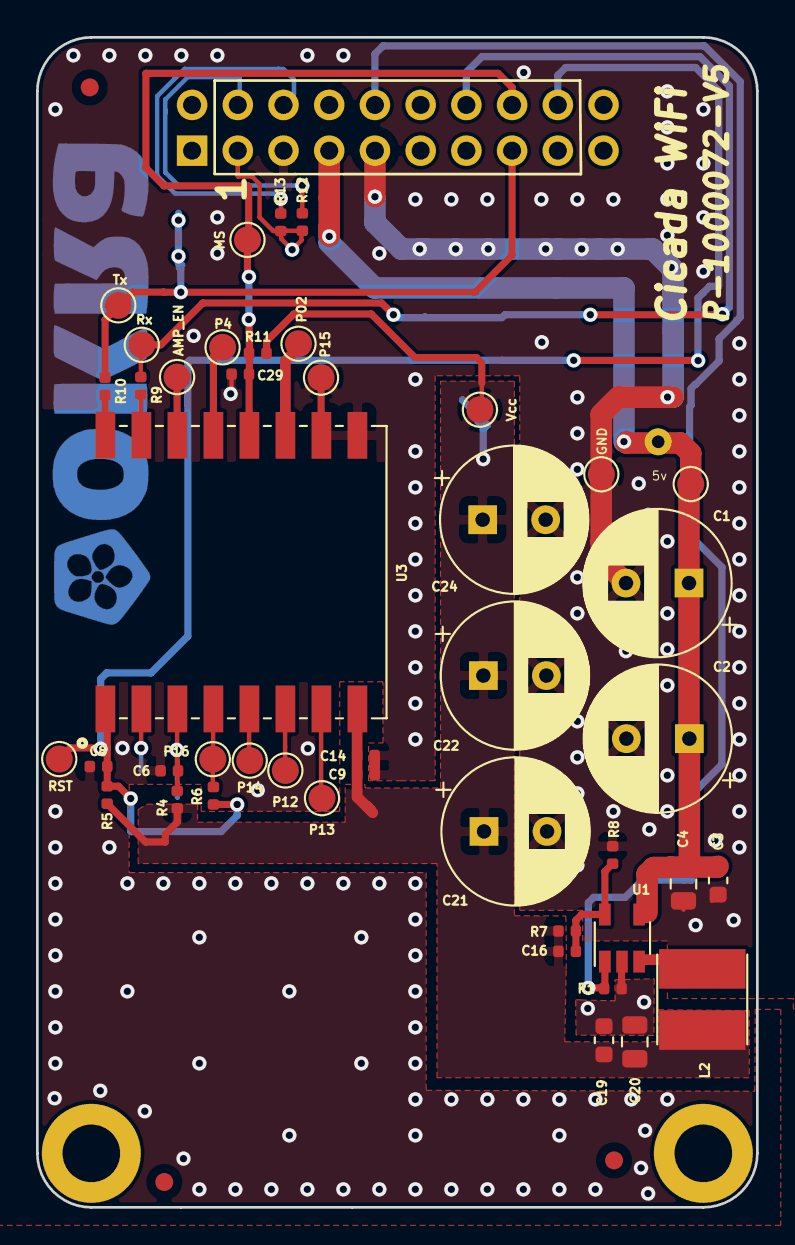
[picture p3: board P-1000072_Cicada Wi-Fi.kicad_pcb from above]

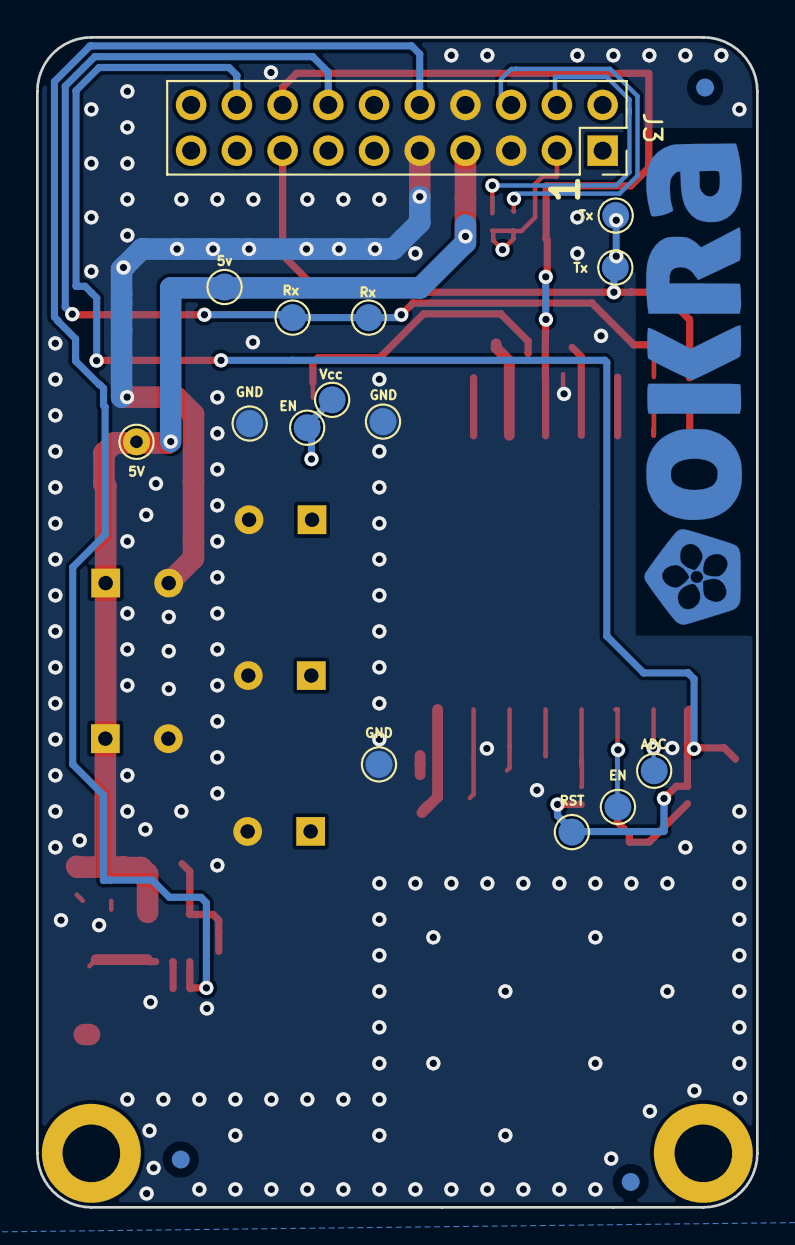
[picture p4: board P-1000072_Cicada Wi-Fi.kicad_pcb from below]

Board: 2 copper layers, 40.0 x 65.0 mm, 68 parts (19 on the bottom side), 24 nets.

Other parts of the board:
5V: 5v; TestPoint_THTPad_D1.5mm_Drill0.7mm
TP39#2: GND; TestPoint_Pad_D1.5mm

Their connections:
/5V0: 5V.1; also elsewhere on the board
GND: TP39#2.1; also elsewhere on the board

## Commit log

2021-11-02 First Commit WiFi Cicada HW design and manufacturing Files
    [P-0000000_PART NAME_BOM.csv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]
2021-11-03 WiFi Cicada First Design and Manufacturing files release
    [P-1000072-V2.3.0_Cicada Wi-Fi-F_Cu.gtl, P-1000072-V2.3.0_Cicada Wi-Fi-F_Mask.gts, P-1000072-V2.3.0_Cicada Wi-Fi-F_Paste.gtp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]
2021-12-24 updated design and manufacturing file version 4.0.0
    [P-1000072-V3.0.0_Cicada Wi-Fi_ECN_.csv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]
2022-01-06 deleted previous production files, reviewed SCH and PCB files
    [P-1000072-V3.0.0_Cicada Wi-Fi-B_CrtYd.gbr, P-1000072-V3.0.0_Cicada Wi-Fi-B_Cu.gbl, P-1000072-V3.0.0_Cicada Wi-Fi-B_Fab.gbr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]
2022-01-19 1.Schematics improvement and crediblity (cleared empty spaces, improved read me and reviewed and cleaned component spec mismatch 2.PCB improments (cleaned top layer copper zones, cleaned vias and upd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
    [P-0000000_PART NAME_BOM.csv, P-1000072-V3.0.0_Cicada Wi-Fi_BOM.csv, P-1000072-V4.0.0_Cicada Wi-Fi_BOM.csv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]
2022-01-20 v4.0.2 Design and Production File ReleaseCleaned up Top and bottom Fabrication layer, Add Bom in seed Studio formate
    [P-1000072-V4.0.1_Cicada Wi-Fi-B_Fab.gbr, P-1000072-V4.0.1_Cicada Wi-Fi-F_Fab.gbr, P-1000072-V4.0.2_Cicada Wi-Fi-B_CrtYd.gbr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]
2022-03-30 P-1000072-V5.1.0_Cicada Wi-Fi Design and Manufacturing files update
    Design update
    1.)Inductor L2 Foot-print dimensions changed to parts commanded Foot-print dimensions(check for more information:design\doc\review\2022-03 Seed studios)
    Manufacturing update
    1.)updated manufacturing output files for the design change (L2 foot-print dimensions)
    [1733170_seeed_dfareporta173154320220228.xlsx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]
2022-04-21 Changes made: -Cleaned up README.md Files -Cleaned design/doc/datasheets removed unwanted datasheets -Cleaned design/source/ removed unwanted files -Added design/source/kicad/OKRA_bom_csv_grouped_by_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
